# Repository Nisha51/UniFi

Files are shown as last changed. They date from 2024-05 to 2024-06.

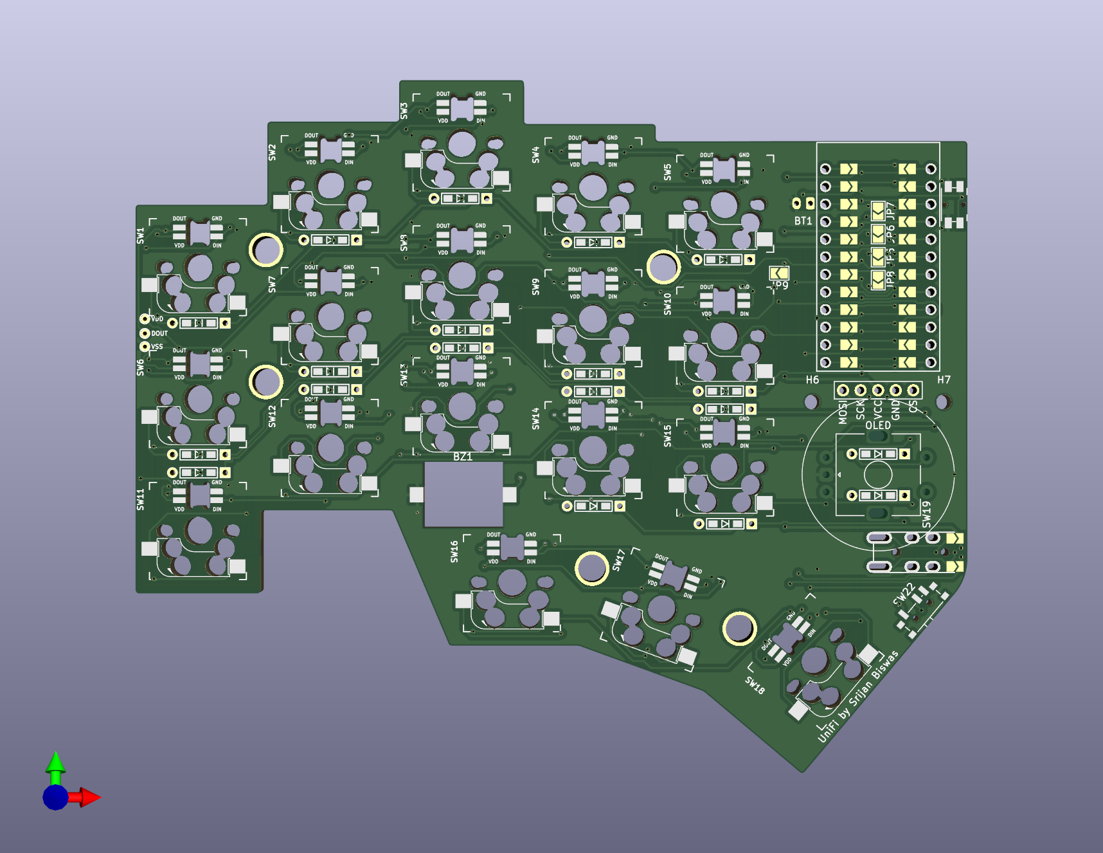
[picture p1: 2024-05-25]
UniFi.png

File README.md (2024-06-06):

**UniFi**

The UniFi is a 36 key split keyboard, that unifies almost all the features found in modern boards in a compact PCB.

It has,
1. OLED and nice!view support.
2. Encoder support.
3. Piezo buzzer support.
4. Both wireless and wired support.
5. Per key RGB with support for underglow.

UniFi

This keyboard was inspired by the FiFi keyboard

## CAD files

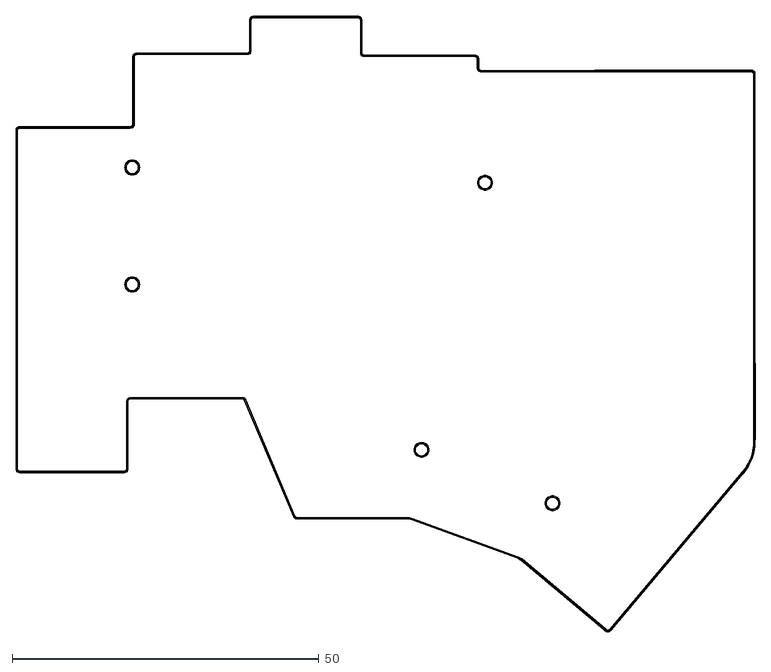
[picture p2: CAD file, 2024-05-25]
Plates/UniFi - Bottom Plate-Edge_Cuts.dxf
120.4 x 100.3

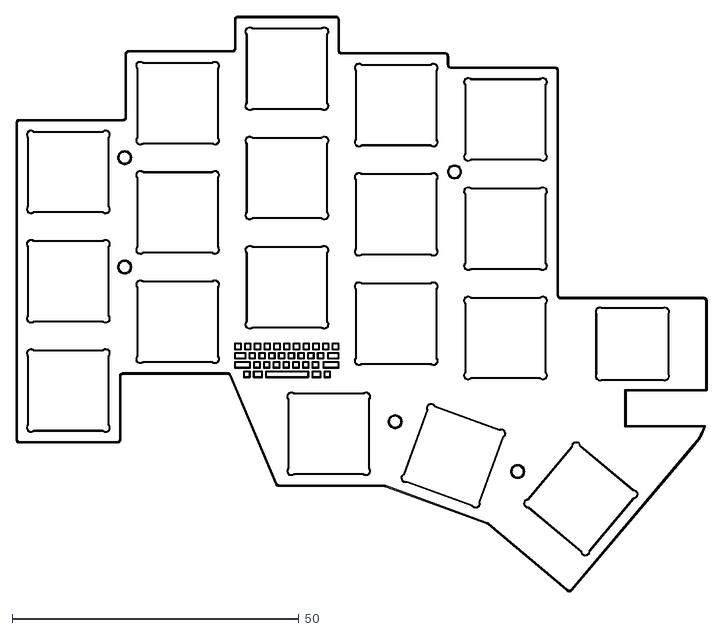
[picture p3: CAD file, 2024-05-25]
Plates/UniFi - Plate.dxf
120.4 x 100.3

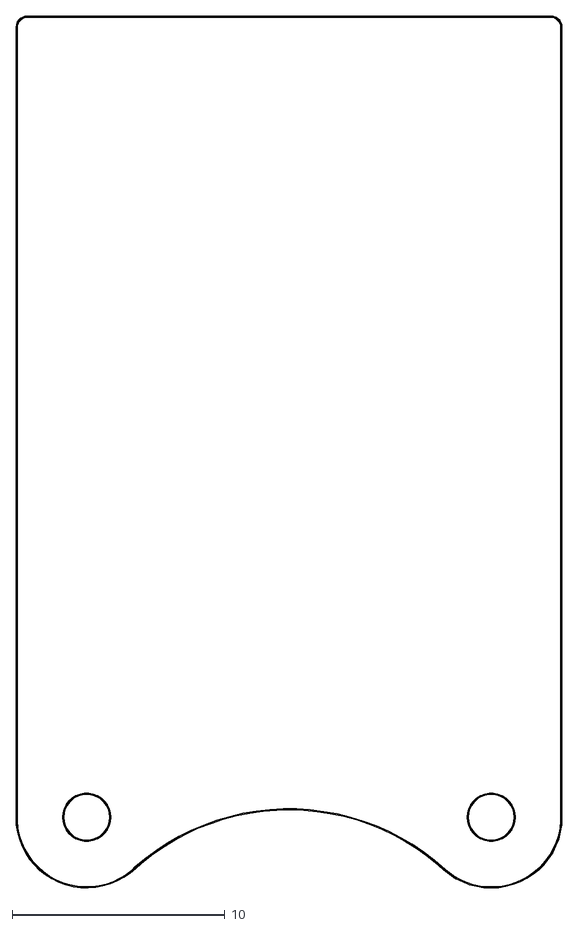
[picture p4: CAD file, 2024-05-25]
Plates/UniFi - Shield-Edge_Cuts.dxf
25.6 x 40.9

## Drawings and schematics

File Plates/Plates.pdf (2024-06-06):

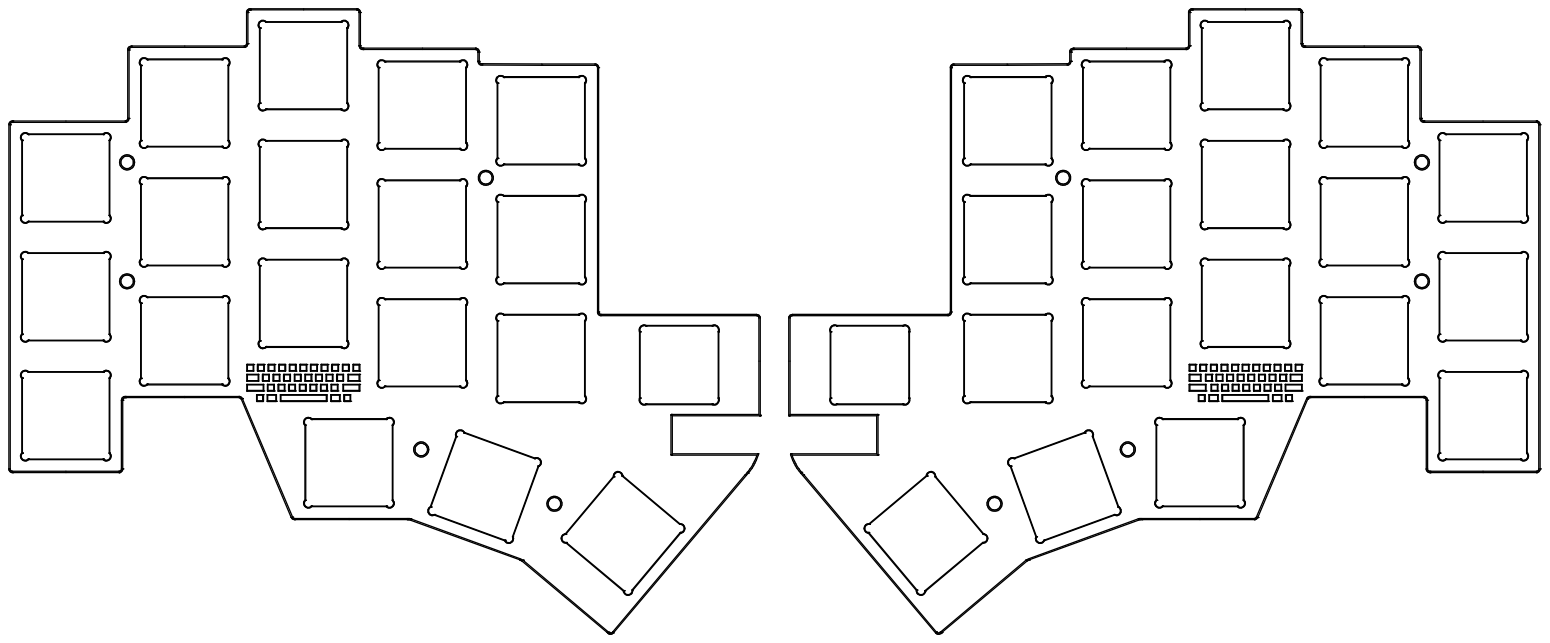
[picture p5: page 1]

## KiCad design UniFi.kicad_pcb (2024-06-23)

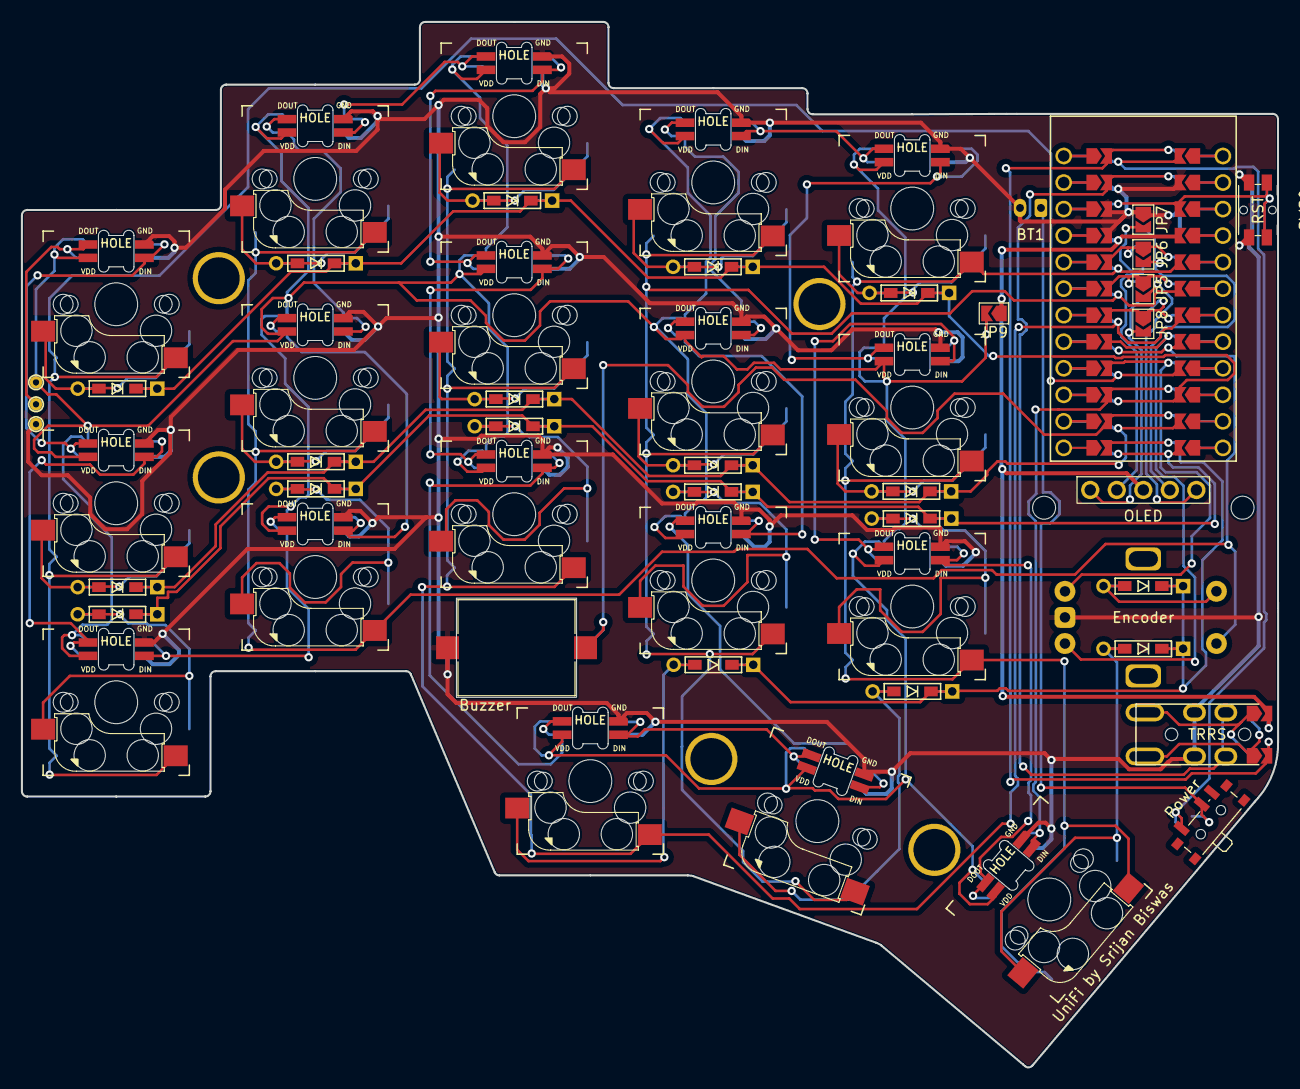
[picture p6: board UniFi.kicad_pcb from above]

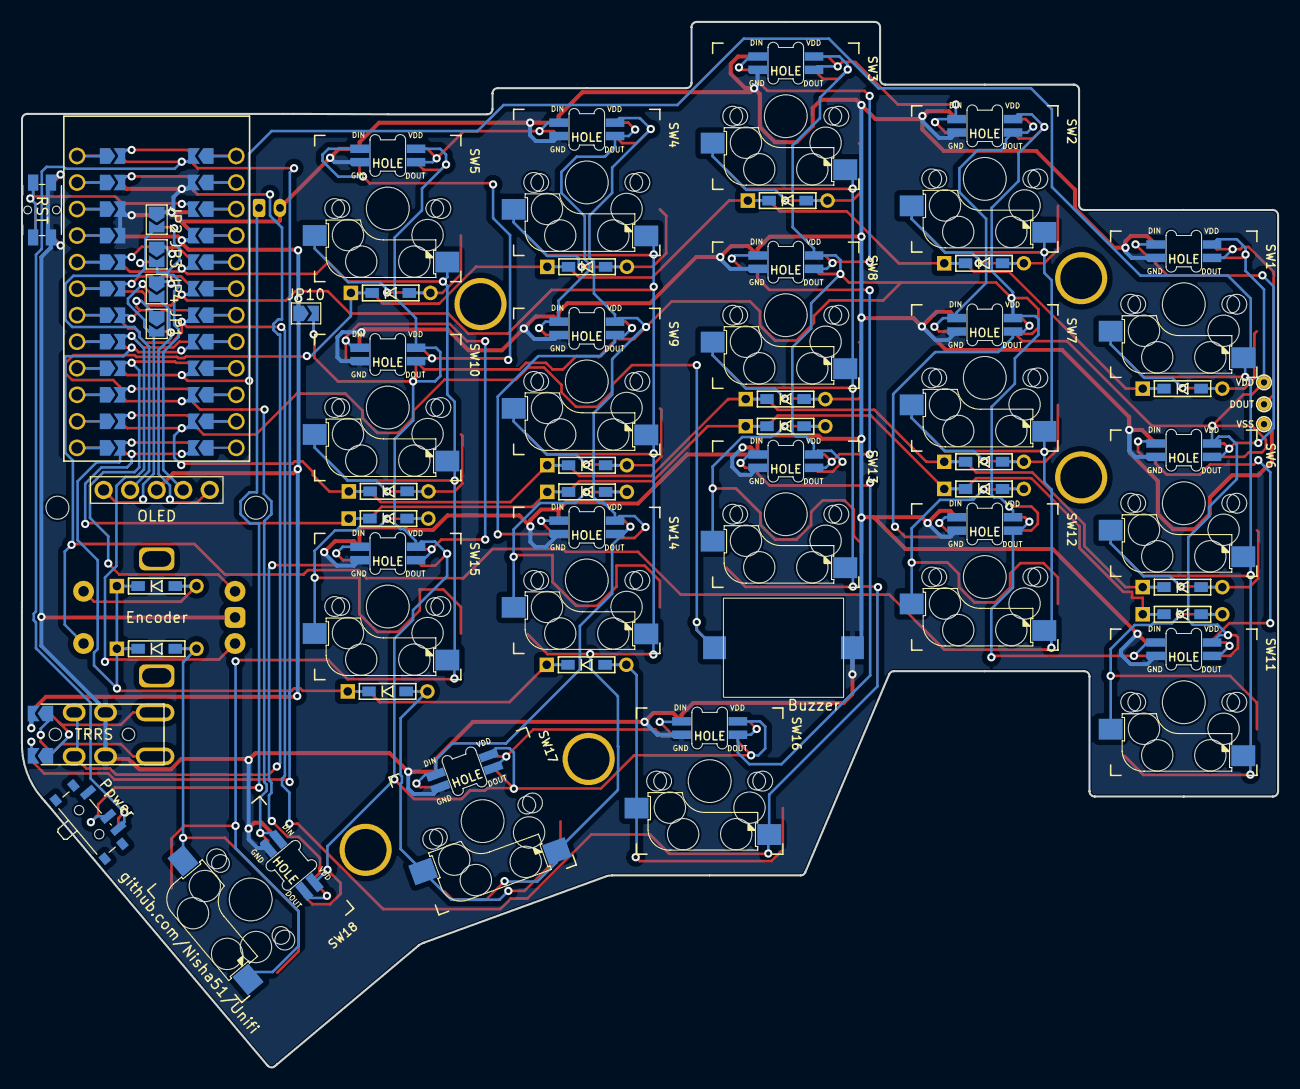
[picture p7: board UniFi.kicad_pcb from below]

Board: 2 copper layers, 120.2 x 100.1 mm, 67 parts (7 on the bottom side), 65 nets.

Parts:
BT1: Battery; JST_PH_S2B-PH-K_1x02_P2.00mm_Horizontal
BZ1: Buzzer; Buzzer_Mallory_AST1109MLTRQ
D1, D2, D3, D4, D5, D6, D7, D8, D9, D10, D11, D12, D13, D14, D15, D16, D17, D18, D19: D; D3_TH_SMD
H1, H2, H3, H4, H5: MountingHole; M2_Hole_TH_Outside
H6, H7: MountingHole; MountingHole_2.2mm_M2
J1: OLED; nice_view
J2: MJ-4PP-9 TRRS; PJ-320A
JP1, JP2, JP3, JP4, JP5, JP6, JP7, JP8, JP9, JP10: Device_Jumper_NO_Small; SolderJumper-2_P1.3mm_Open_TrianglePad1.0x1.5mm
Power: SW_SPDT; SW_SPDT_PCM12
Ppwer: SW_SPDT; SW_SPDT_PCM12
SW1, SW2, SW3, SW4, SW5, SW6, SW7, SW8, SW9, SW10, SW11, SW12, SW13, SW14, SW15, SW16, SW17, SW18: SW_PUSH-MX_W_LED; SK6812MINI_e_and_cherry
SW19: RotaryEncoder_Switch; ROT_Alps_EC11E-Switch
SW20, SW21: Push_Button; Panasonic_EVQPUL_EVQPUC
TP1: VDD; TestPoint
TP2: DOUT; TestPoint
TP3: VSS; TestPoint
U1: ProMicro_NiceNano_EliteC; ProMicro_unrouted_flipped

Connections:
AUDIO: BZ1.1 (-), U1.11 (B4)
BAT+: Power.1 (A), Ppwer.3 (C), U1.24 (B0/VBUS)
COL1: SW1.6, SW6.6, SW11.6, U1.16 (B1)
COL2: SW2.6, SW7.6, SW12.6, SW19.S1, U1.17 (F7)
COL3: SW3.6, SW8.6, SW13.6, SW16.6, U1.18 (F6)
COL4: SW4.6, SW9.6, SW14.6, SW17.6, U1.19 (F5)
COL5: SW5.6, SW10.6, SW15.6, SW18.6, U1.20 (F4)
CS: JP1.1, JP8.1, U1.7 (D4)
ECA: SW19.A, U1.9 (D7)
ECB: SW19.B, U1.8 (C6)
ECR: D19.2 (A), SW19.S2
GND: BT1.2 (-), BZ1.2 (+), J2.4, JP2.1, JP7.1, SW1.3 (GND), SW2.3 (GND), SW3.3 (GND), SW4.3 (GND), SW5.3 (GND), SW6.3 (GND), SW7.3 (GND), SW8.3 (GND), SW9.3 (GND), SW10.3 (GND), SW11.3 (GND), SW12.3 (GND), SW13.3 (GND), SW14.3 (GND), SW15.3 (GND), SW16.3 (GND), SW17.3 (GND), SW18.3 (GND), SW19.C, SW20.2, SW21.2, TP3.1, U1.3 (GND), U1.4 (GND), U1.23 (GND)
LED: SW18.4 (DIN), U1.10 (E6)
unnamed: BT1.1 (+), Power.2 (B), Ppwer.2 (B)
unnamed: D1.2 (A), SW1.5
unnamed: D2.2 (A), SW2.5
unnamed: D3.2 (A), SW3.5
unnamed: D4.2 (A), SW4.5
unnamed: D5.2 (A), SW5.5
unnamed: D6.2 (A), SW6.5
unnamed: D7.2 (A), SW7.5
unnamed: D8.2 (A), SW8.5
unnamed: D9.2 (A), SW9.5
unnamed: D10.2 (A), SW10.5
unnamed: D11.2 (A), SW11.5
unnamed: D12.2 (A), SW12.5
unnamed: D13.2 (A), SW13.5
unnamed: D14.2 (A), SW14.5
unnamed: D15.2 (A), SW15.5
unnamed: D16.2 (A), SW16.5
unnamed: D17.2 (A), SW17.5
unnamed: D18.2 (A), SW18.5
unnamed: J1.1, JP4.2, JP8.2
unnamed: J1.2, JP3.2, JP7.2
unnamed: J1.4, JP2.2, JP6.2
unnamed: J1.5, JP1.2, JP5.2
unnamed: SW1.4 (DIN), SW6.2 (DOUT)
unnamed: SW1.2 (DOUT), TP2.1
unnamed: SW2.4 (DIN), SW3.2 (DOUT)
unnamed: SW2.2 (DOUT), SW7.4 (DIN)
unnamed: SW3.4 (DIN), SW8.2 (DOUT)
unnamed: SW4.4 (DIN), SW5.2 (DOUT)
unnamed: SW4.2 (DOUT), SW9.4 (DIN)
unnamed: SW10.4 (DIN), SW15.2 (DOUT)
unnamed: SW5.4 (DIN), SW10.2 (DOUT)
unnamed: JP9.2, JP10.2, SW1.1 (VDD), SW2.1 (VDD), SW3.1 (VDD), SW4.1 (VDD), SW5.1 (VDD), SW6.1 (VDD), SW7.1 (VDD), SW8.1 (VDD), SW9.1 (VDD), SW10.1 (VDD), SW11.1 (VDD), SW12.1 (VDD), SW13.1 (VDD), SW14.1 (VDD), SW15.1 (VDD), SW16.1 (VDD), SW17.1 (VDD), SW18.1 (VDD), TP1.1
unnamed: SW11.4 (DIN), SW12.2 (DOUT)
unnamed: SW6.4 (DIN), SW11.2 (DOUT)
unnamed: SW7.2 (DOUT), SW12.4 (DIN)
unnamed: SW13.4 (DIN), SW16.2 (DOUT)
unnamed: SW8.4 (DIN), SW13.2 (DOUT)
unnamed: SW9.2 (DOUT), SW14.4 (DIN)
unnamed: SW14.2 (DOUT), SW17.4 (DIN)
unnamed: SW15.4 (DIN), SW18.2 (DOUT)
unnamed: SW16.4 (DIN), SW17.2 (DOUT)
RESET: SW20.1, SW21.1, U1.22 (RST)
ROW1: D1.1 (K), D2.1 (K), D3.1 (K), D4.1 (K), D5.1 (K), U1.15 (B3)
ROW2: D6.1 (K), D7.1 (K), D8.1 (K), D9.1 (K), D10.1 (K), U1.14 (B2)
ROW3: D11.1 (K), D12.1 (K), D13.1 (K), D14.1 (K), D15.1 (K), U1.13 (B6)
ROW4: D16.1 (K), D17.1 (K), D18.1 (K), D19.1 (K), U1.12 (B5)
RX: J2.2, U1.2 (RX)
SCL: JP3.1, JP6.1, U1.5 (SCL)
SDA: JP4.1, JP5.1, U1.6 (SDA)
TX: J2.1, U1.1 (TX)
VCC: J1.3, J2.3, JP9.1, JP10.1, U1.21 (VCC)

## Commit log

2024-04-25 Updated pcb
2024-04-25 Updated TRRS
    [UniFi.kicad_pcb]
2024-05-25 Added Plates
    [UniFi - Bottom Plate-Edge_Cuts.dxf, UniFi - Bottom Plate.kicad_pcb, UniFi - Plate-Edge_Cuts.dxf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]
2024-06-06 Updated Plate
    [UniFi - Bottom Plate.kicad_pcb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]
2024-06-12 Updated pins
    [UniFi-B_Cu.gbr, UniFi-B_Mask.gbr, UniFi-B_Silks.gbr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]
2024-06-23 Added References
    [UniFi.kicad_pcb]
